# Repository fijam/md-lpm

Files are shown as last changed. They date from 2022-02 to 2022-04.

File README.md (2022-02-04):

# md-lpm

This project consists of hardware files and software for a coin-battery operated laser tester that fits in a MiniDisk case.



## Hardware

Schematics, BOM and PCB layout files are available in the hardware directory.

## Theory of operation

This is the nerdy bit, feel free to skip ahead.

The heart of this device is a silicon PIN photodiode (BPW34) operated in reverse-biased mode, which generates current proportional to light intensity. The MiniDisc standard uses 780nm near-infrared laser source for both playback (using the magneto-optic Kerr effect) and recording (for heating up the disc to its Curie temperature). The output power spans between 0.5 and 9mW, depending on the device. 

The selected photodiode has approx. 95% spectral sensitivity at 780nm. The reverse voltage of 3V from a manganese-dioxide lithium battery and load resistance of 1k Ohm allows for a linear response up to 5.5mW as given by: 
`Psat = (0.3 + VR)/RL * S` where VR is the reverse voltage [2.9 V], S is the photosensitivity at 780nm [0.58 A/W] and RL is the load resistance [1000 Ohm]. Photodiode series resistance is disregarded.

High correlation between the photodiode readout (10b referenced to Vdd) and the device refPw setting (in decimal) is achieved:



Shorter fragments of this polynomial (around 0.5-1mW for LrefPw/HrefPw and 4.5-5.5mW for WritPW) can be approximated with a linear regression. 

To discount the effect of battery voltage dropping as it discharges, internal voltage reference of 1.1V is used for LrefPw/HrefPw. For WritPw, the whole range of Vdd is used. The setting of WritPw does not require a high precision.

Each device comes with a calibration factor saved in `user_row` area of the EEPROM which is protected from accidental chip erase. This calibration factor (by default 100%) accounts for differences between components, photodiode alignment and assembly in the minidisc case. It is taken into account when calculating LrefPw and HrefPw.

The firmware of the microcontroller is configured with a BOD of ~2.6V which prevents the device from running on a discharged battery.

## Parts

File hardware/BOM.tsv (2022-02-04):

Id | Designator | Package | Quantity | Designation | Supplier and ref
1 | R8 | R_1206_3216Metric_Pad1.30x1.75mm_HandSolder | 1 | 100k
2 | R1 | R_1206_3216Metric_Pad1.30x1.75mm_HandSolder | 1 | 249k
3 | C2 | CP_EIA-3528-21_Kemet-B_Pad1.50x2.35mm_HandSolder | 1 | 68uF | Optional | Kemet T case
4 | SW1 | SW_SP3T_PCM13 | 1 | SW_SP3T | Nidec Copal CUS-13TB
5 | D1,D4 | LED_Avago_PLCC4_3.2x2.8mm_CW_datasheet | 2 | LED_Dual_ACAC | Avago HSMF-C155
6 | U1 | SOIC-8_3.9x4.9mm_P1.27mm | 1 | ATtiny412-SS | Microchip ATTINY212-SSNR
7 | C1 | C_1206_3216Metric_Pad1.33x1.80mm_HandSolder | 1 | 100nF
8 | D3 | Osram_SMD-DIL2_4.5x4.0mm | 1 | BPW34-SMD | Osram BPW34S
9 | R2,R3,R4 | R_1206_3216Metric_Pad1.30x1.75mm_HandSolder | 3 | 220
10 | R5 | R_1206_3216Metric_Pad1.30x1.75mm_HandSolder | 1 | 1k
11 | R7 | R_1206_3216Metric_Pad1.30x1.75mm_HandSolder | 1 | 480k

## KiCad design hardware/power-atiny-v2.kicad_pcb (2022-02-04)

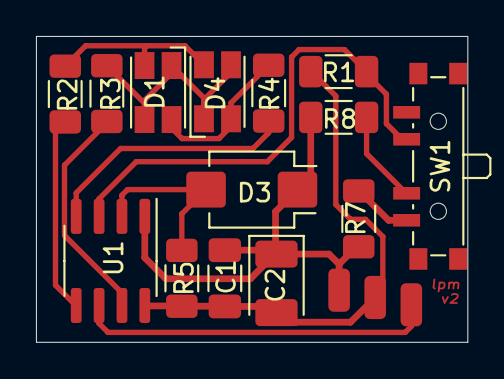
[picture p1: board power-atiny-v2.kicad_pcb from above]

Board: 2 copper layers, 24.0 x 17.0 mm, 17 parts (0 on the bottom side), 13 nets.

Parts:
C1: 100nF; C_1206_3216Metric_Pad1.33x1.80mm_HandSolder
C2: 68uF; CP_EIA-3528-21_Kemet-B_Pad1.50x2.35mm_HandSolder
D1, D4: LED_Dual_ACAC; LED_Avago_PLCC4_3.2x2.8mm_CW_datasheet
D3: BPW34-SMD; Osram_SMD-DIL2_4.5x4.0mm
GND: SolderWirePad_1x01_SMD_1x2mm
R1: 249k; R_1206_3216Metric_Pad1.30x1.75mm_HandSolder
R2, R3, R4: 220; R_1206_3216Metric_Pad1.30x1.75mm_HandSolder
R5: 1k; R_1206_3216Metric_Pad1.30x1.75mm_HandSolder
R7: 480k; R_1206_3216Metric_Pad1.30x1.75mm_HandSolder
R8: 100k; R_1206_3216Metric_Pad1.30x1.75mm_HandSolder
SW1: SW_SP3T; SW_SP3T_PCM13
U1: ATtiny412-SS; SOIC-8_3.9x4.9mm_P1.27mm
UPDI: SolderWirePad_1x01_SMD_1x2mm
VCC: SolderWirePad_1x01_SMD_1x2mm

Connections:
GND: C1.2, C2.2, GND.1, R1.2, R5.2, U1.8
unnamed: D1.1, D1.4, D4.1, D4.4, R3.1
unnamed: D1.2, D4.3, R2.1
unnamed: D1.3, D4.2, R4.1
unnamed: D3.2, R5.1, U1.2
unnamed: R1.1, SW1.3, U1.3
unnamed: R2.2, U1.5
unnamed: R3.2, U1.7
unnamed: R4.2, U1.4
unnamed: R7.2, SW1.1
unnamed: R8.2, SW1.2
unnamed: U1.6, UPDI.1
VCC: C1.1, C2.1, D3.1, R7.1, R8.1, U1.1, VCC.1

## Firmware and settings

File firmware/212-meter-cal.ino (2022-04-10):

#include <avr/sleep.h>
#include <EEPROM.h>
#include <USERSIG.h>

const byte LEDL = 15;
byte previousState = 0;
byte currentState = 0;
byte calFactor = 100;
uint16_t highestADC = 0;
uint16_t currentADC = 0;
uint16_t correctedVal = 0;
uint16_t loopCount = 0;

ISR(RTC_PIT_vect) {
  RTC.PITINTFLAGS = RTC_PI_bm;          // Clear interrupt flag
}

ISR(PORTA_PORT_vect) {
  _PROTECTED_WRITE(RSTCTRL.SWRR,1);     // we have been woken up from long sleep, reset
}

void RTC_arm(void) {                     // Arming the nugget
  while (RTC.STATUS > 0)
  {
    ;                                   // Wait for all registers to synchronize
  }
  RTC.CLKSEL = RTC_CLKSEL_INT32K_gc;    // 32.768kHz Internal Ultra-Low-Power Oscillator (OSCULP32K)
  RTC.PITINTCTRL = RTC_PI_bm;           // PIT Interrupt: enabled
  RTC.PITCTRLA = RTC_PERIOD_CYC4096_gc  // RTC Clock Cycles 8192, resulting in 32.768kHz/4096 = 8Hz
                 | RTC_PITEN_bm;        // Enable PIT counter: enabled
}

void RTC_disarm() {
  RTC.PITCTRLA = RTC_PERIOD_OFF_gc &~ RTC_PITEN_bm;
}

void prepareSleep() {                   // don't leave any pins floating before going to sleep
  digitalWriteFast(2, LOW);
  pinModeFast(2, OUTPUT);
  digitalWriteFast(3, LOW);
  pinModeFast(3, OUTPUT);
  digitalWriteFast(4, LOW);
  pinModeFast(4, OUTPUT);
}

void pinModeCharlieOne() {              // saves a few bytes
  pinModeFast(3, OUTPUT);
  pinModeFast(4, OUTPUT);
  pinModeFast(2, INPUT);
}

void pinModeCharlieTwo() {
  pinModeFast(3, INPUT);
  pinModeFast(4, OUTPUT);
  pinModeFast(2, OUTPUT);
}

void leftred() {                         // all the LED combinations
  pinModeCharlieOne();
  digitalWriteFast(4, LOW);
  digitalWriteFast(3, HIGH);
  delay(LEDL);
  digitalWriteFast(3, LOW);
}

void leftgreen() {
  pinModeCharlieTwo();
  digitalWriteFast(2, LOW);
  digitalWriteFast(4, HIGH);
  delay(LEDL);
  digitalWriteFast(4, LOW);
}

void rightgreen() {
  pinModeCharlieOne();
  digitalWriteFast(3, LOW);
  digitalWriteFast(4, HIGH);
  delay(LEDL);
  digitalWriteFast(4, LOW);
}

void rightred() {
  pinModeCharlieTwo();
  digitalWriteFast(4, LOW);
  digitalWriteFast(2, HIGH);
  delay(LEDL);
  digitalWriteFast(2, LOW);
}

void leftyellow () {                      // LED helpers
  leftred();
  leftgreen();
}

void rightyellow () {
  rightred();
  rightgreen();
}

void bothgreen () {
  rightgreen();
  leftgreen();
}

byte checkswitch() {                                 // voltage divider cutoffs: 0, 360, 725
  uint16_t switchState = analogRead(1);
  if (switchState < 50) {                            // high switch setting  - WritPw
    return 3;
  }
  if (switchState > 335 && switchState < 385) {      // low switch setting - LrefPw
    return 1;
  }
  if (switchState > 700 && switchState < 750) {      // middle switch setting - HrefPw
    return 2;
  }
  return 0;                                          // something went wrong
}

byte checkswitchDb() {                                // deliberately debounce with delay so we can decide before sleeping for 125ms
  analogReference(VDD);
  analogRead(1);                                      // discard first readout
  byte switchCounter = 0;
  byte currentReading = checkswitch();
  byte lastState = 0;

  for (byte i = 0; i <= 4; i++) {
    lastState = currentReading;
    delay(3);
    currentReading = checkswitch();
    if (lastState == currentReading) switchCounter++;
  }
  if (switchCounter == 5) {                            // if we got 5 identical readings in 15ms then we are good
    return currentReading;
  }
  else {                                               // we try again next time
    return 0;
  }
}

void setup() {

  set_sleep_mode(SLEEP_MODE_PWR_DOWN);                  // prepare sleep mode
  sleep_enable();
  RTC_arm();                                            // prepare PIT/RTC to wake up later

  pinModeFast(0, INPUT);                                // photodiode
  pinModeFast(1, INPUT);                                // switch
  pinModeFast(2, INPUT);                                // charlieplex
  pinModeFast(3, INPUT);                                // charlieplex
  pinModeFast(4, INPUT);                                // charlieplex
  // 5 is UPDI

  analogReference(VDD);                                 // save battery voltage level
  VREF.CTRLA = VREF_ADC0REFSEL_1V5_gc;
  analogSampleDuration(13);                             // no rush
  uint16_t battery = analogRead(ADC_INTREF);            // discard
  battery = analogRead(ADC_INTREF);
  EEPROM.put(48, battery);                              // battery goes to EEPROM offset 48

  analogReference(INTERNAL2V5);                         // reset ADC reference

  calFactor = USERSIG.read(0);                          // read device calibration factor
  // this region of EEPROM is safe from chip erase
  
  leftred();                                            // LED check
  leftgreen();
  rightgreen();
  rightred();

}

void loop() {
  currentState = checkswitchDb();
  if (currentState != previousState) {                 // switch has moved since last time, we have work to do
    switch (previousState) {                           // save the last sensor reading to EEPROM
      case 3:                                          // Writ goes to EEPROM offset 0
        EEPROM.put(0, highestADC);
        break;
      case 2:                                          // Href goes to offset 16
        EEPROM.put(16, highestADC);
        break;
      case 1:                                          // Lref goes to offset 32
        EEPROM.put(32, highestADC);
        break;
    }
    highestADC = 0;                                    // reset global counters
    loopCount = 0;
    switch (currentState) {                            // blink LED to indicate a change was noted
      case 1:
        rightred();
        break;
      case 2:
        rightyellow();
        break;
      case 3:
        rightgreen();
        break;
    }
    previousState = currentState;
  }

  switch (currentState) {                               // use appropriate reference for switch state
    case 1:
      analogReference(INTERNAL1V1);
      break;
    case 2:
      analogReference(INTERNAL1V1);
      break;
    case 3:
      analogReference(VDD);                             // full range of ADC needed to reach 5mW
      break;
  }
  currentADC = analogRead(0);                           // discard
  currentADC = analogRead(0);                           // keep track of highest recorded value on photodiode
  if (currentADC > highestADC) {
    highestADC = currentADC;
  }
  
  loopCount++;
  if (loopCount % 12 == 0) {                             // every 12 measurements (~1.8 second) indicate result
    switch (currentState) {
      case 1:                                            // LRef
      correctedVal = (highestADC * calFactor);
        if (correctedVal < 25900) leftred();
        if (correctedVal >= 25900 && correctedVal < 29500) leftyellow();
        if (correctedVal >= 29500 && correctedVal < 33100) leftgreen();
        if (correctedVal >= 33100 && correctedVal < 40400) bothgreen();
        if (correctedVal >= 40400 && correctedVal < 44000) rightgreen();
        if (correctedVal >= 44000 && correctedVal < 47700) rightyellow();
        if (correctedVal >= 47700) rightred();
        break;
      case 2:                                             // Href
      correctedVal = (highestADC * calFactor);
        if (correctedVal < 30400) leftred();
        if (correctedVal >= 30400 && correctedVal < 35000) leftyellow();
        if (correctedVal >= 35000 && correctedVal < 39500) leftgreen();
        if (correctedVal >= 39500 && correctedVal < 48600) bothgreen();
        if (correctedVal >= 48600 && correctedVal < 53100) rightgreen();
        if (correctedVal >= 53100 && correctedVal < 57700) rightyellow();
        if (correctedVal >= 57700) rightred();
        break;
      case 3:                                              // Writ
      // no need for high accuracy
        if (highestADC < 720) leftred();
        if (highestADC >= 720 && highestADC < 780) leftyellow();
        if (highestADC >= 780 && highestADC < 840) leftgreen();
        if (highestADC >= 840 && highestADC < 960) bothgreen();
        if (highestADC >= 960 && highestADC < 1020) rightgreen();
        // if (highestADC >= 980 && highestADC < 1020) rightyellow(); we run out of range
        if (highestADC >= 1020) rightred();
        break;
    }

    if (currentState == 3 && loopCount % 4500 == 0) {       // if user hasn't done anything for ~10 minutes 
      rightred();                                           // express displeasure
      leftred();
      RTC_disarm();                                         // sleep until woken from switch interrupt
      PORTA.PIN7CTRL  = 0b00000001;      
   }

  }
  prepareSleep();
  sleep_cpu(); // wait for the prince's kiss
}

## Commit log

2022-02-04 Initial import
    [power-atiny-v2.kicad_pcb, power-atiny-v2.sch]
2022-02-04 Add BOM
    [BOM.csv]
2022-02-04 use tab separator for BOM
    [BOM.csv, BOM.tsv]
